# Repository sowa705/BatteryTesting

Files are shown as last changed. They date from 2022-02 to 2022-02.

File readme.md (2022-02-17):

# Simple battery testing tool

This project aims to build a **complete** and affordable setup for DIY battery testing.

## Features

* Compatible with various battery types
* Battery capacity testing
* Internal resistance measurement
* Nice graphs
* Minimal component count, low cost

## Example test result

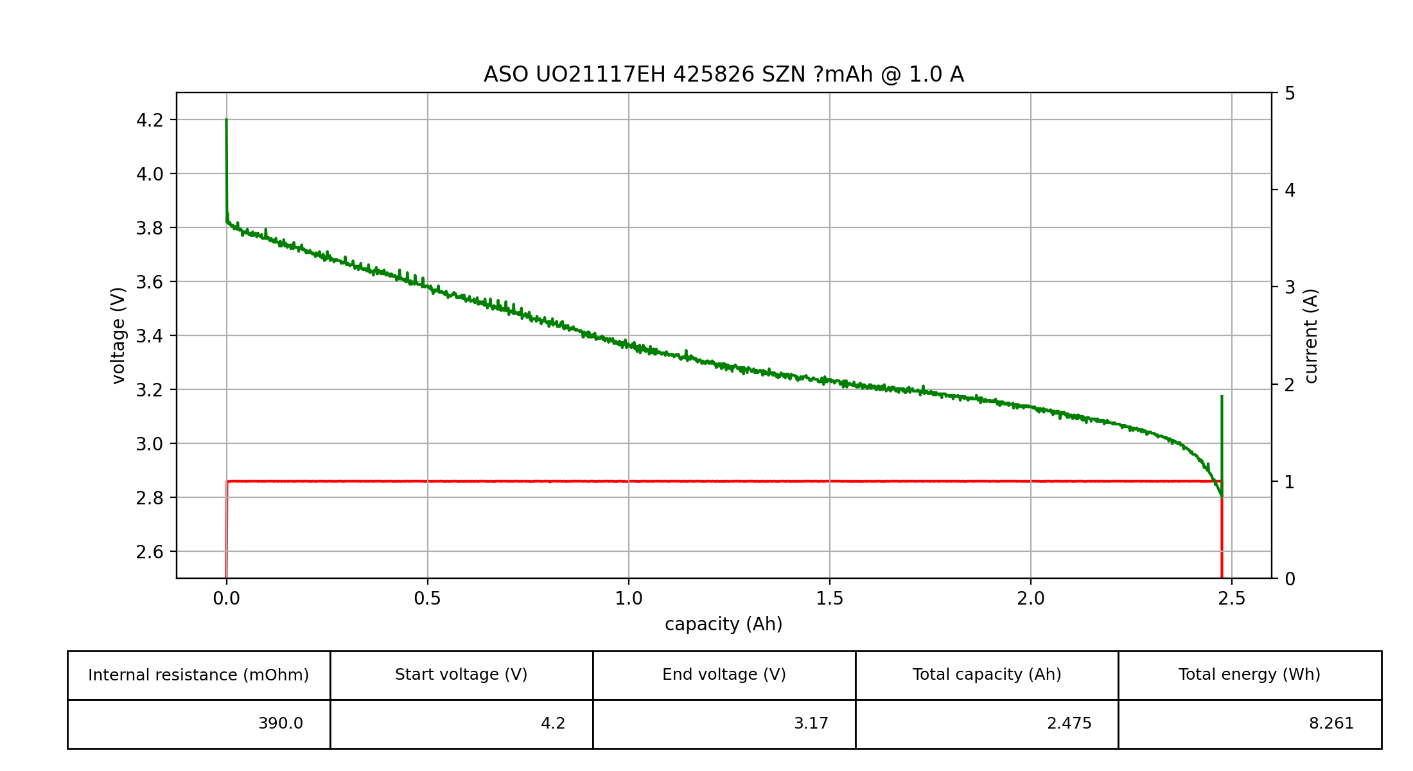
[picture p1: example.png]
Example test result


## Required parts

* Computer with Python 3
* Arduino Uno
* Constant current load (example schematic included in the hardware directory)

## Usage

* Connect all parts together (load is not applied until the software is started)
* Start the measurement with `python .\desktop\measurebattery.py [COM PORT] [CUTOFF VOLTAGE]`
* Battery will be discharged until it reaches specified voltage or *2.8V* if no voltage was specified
* Enter your battery name in the first line of the resulting file ( `battery_[TIME].txt` )
* Render the graph with `python .\desktop\rendergraph.py [FILE NAME]`

## Accuracy

Measurement accuracy depends heavily on how stable your PC USB voltage is, after calibration you should be able to get around 5% accuracy for capacity.

Accurate measurement of internal resistance requires good battery connection and good PCB design for your constant current load, stock design should be able to measure within 10%.

## Contributing

Contributions are welcome, feel free to submit your own test results or hardware/software improvements.

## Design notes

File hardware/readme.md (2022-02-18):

# Hardware

This section is unfinished as I wait for parts for the more advanced board to arrive.

As a temporary solution you can use the circuit in the `manualcurrent` directory

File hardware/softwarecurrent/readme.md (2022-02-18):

# Software current control board design

This directory contains the Eagle PCB design files for the Arduino shield with all required hardware installed

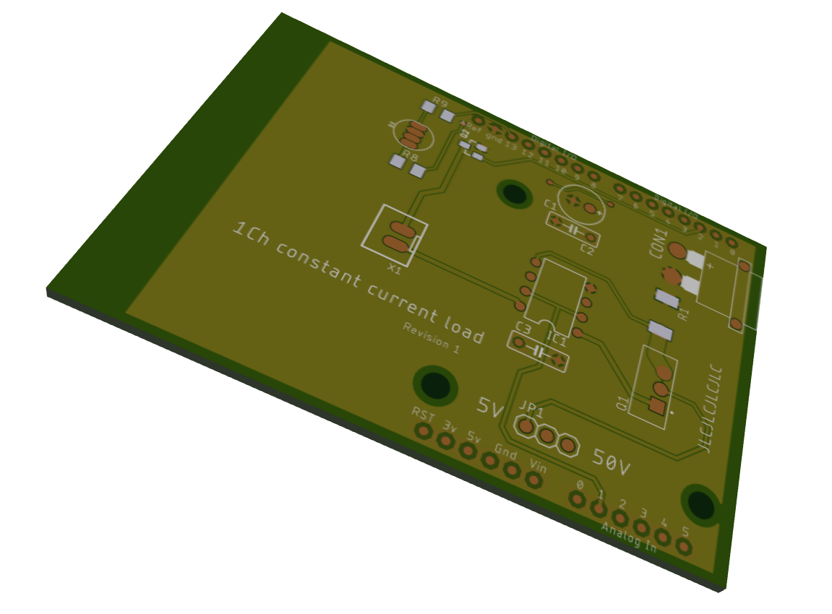
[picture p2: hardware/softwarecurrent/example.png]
PCB picture


## Features

* Arduino shield format
* Software adjustable load
* Wide voltage range (0V - 50V)
* Active cooling

## Support

This PCB isn't yet supported as i wait for it to ship from China, this page will be updated when i get the software and hardware ready to use.

BOM and additional information will be available soon.

## Usage

**If your battery voltage exceeds 5V set the voltage switch to the "50V" position to enable the voltage divider.**

Connect your battery to the XT30 connector on the board, all further setup is done through software.

## Considerations

* This board heavily depends on reliable 5V power supply for the Arduino, with unstable voltage your results may drift considerably
* Watch out for the mosfet temperature, while this board has a fan connector you can easily overload it by discharging high currents from high voltage batteries

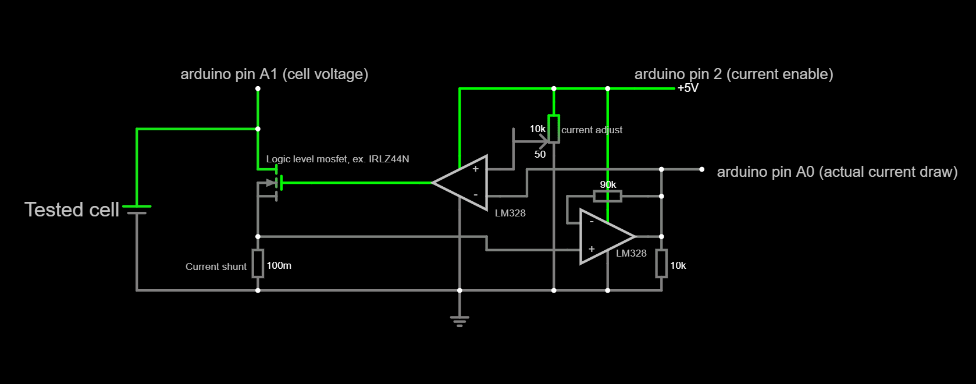
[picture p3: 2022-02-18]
hardware/manualcurrent/basicschematic.png

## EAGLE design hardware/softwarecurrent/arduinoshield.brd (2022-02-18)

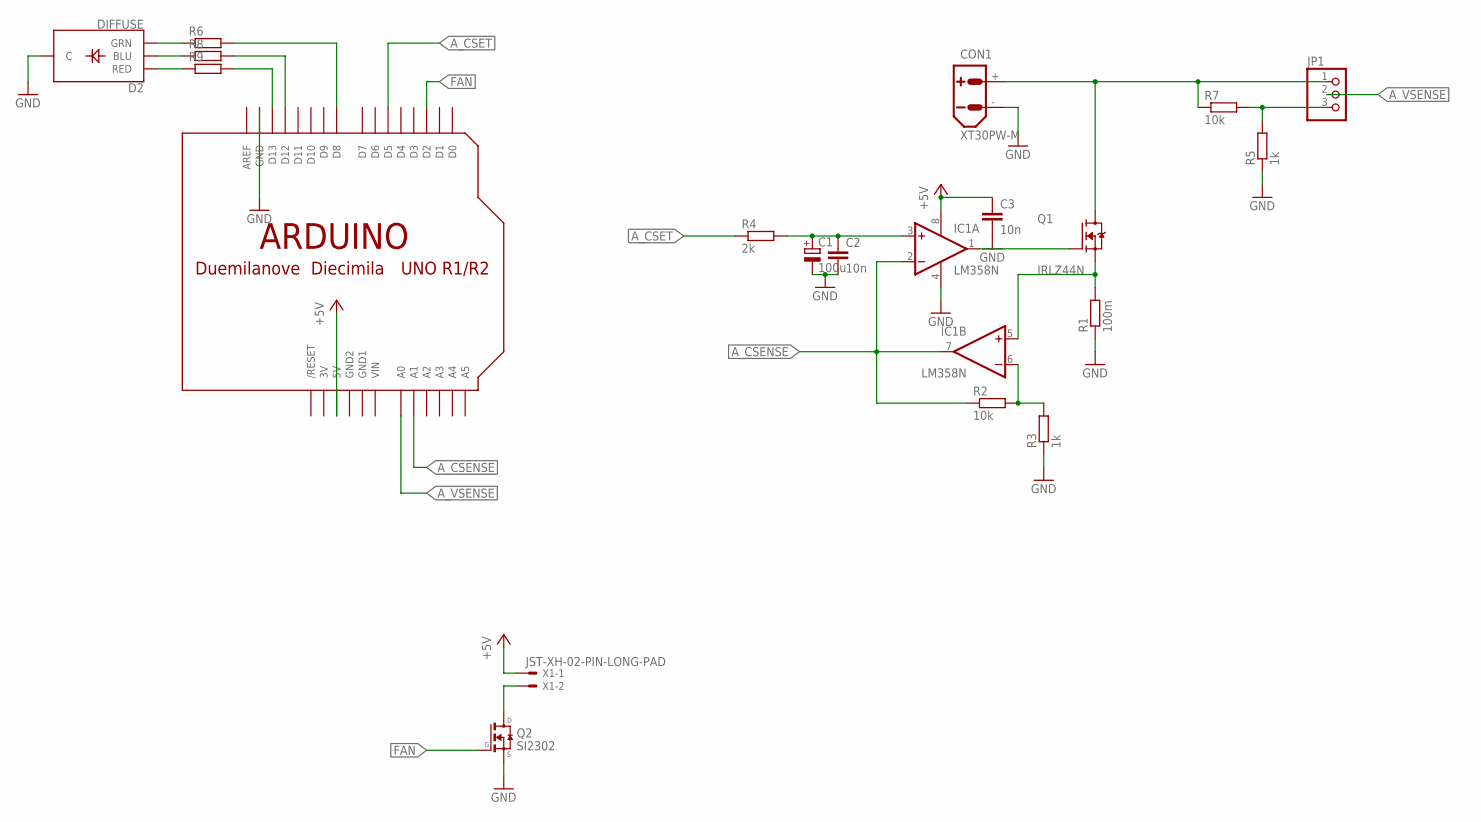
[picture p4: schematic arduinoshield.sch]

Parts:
C1: 100u; E2,5-7
C2, C3: 10n; C050-025X075
CON1: XT30PW-M
D2: DIFFUSE; LED-RGB-THRU
IC1: LM358N; DIL08
JP1: PINHD-1X3; 1X03
Q1: IRLZ44N; TO254P1054X469X1930-3
Q2: SI2302; SOT23
R1: 100m; R2512
R2, R7: 10k; M1206
R3, R5: 1k; M1206
R4: 2k; M1206
R6, R8, R9: R-EU_M1206; M1206
U$2: ARDUINO-NOHOLE
X1: JST-XH-02-PIN-LONG-PAD; JST-XH-02-PACKAGE-LONG-PAD

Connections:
3V: U$2.3V
+5V: C3.1, IC1.8 (V+), U$2.5V, X1.1
A_CSENSE: IC1.2 (-IN), IC1.7 (OUT), R2.1, U$2.A1
A_CSET: R4.1, U$2.D5
A_VSENSE: JP1.2, U$2.A0
FAN: Q2.1 (G), U$2.D2
GND: C1.-, C2.2, C3.2, CON1.-, D2.2 (C), IC1.4 (V-), Q2.2 (S), R1.1, R3.1, R5.1, U$2.GND
GND1: U$2.GND1
GND2: U$2.GND2
unnamed: IC1.5 (+IN), Q1.3 (S), R1.2
unnamed: CON1.+, JP1.1, Q1.2 (D), R7.1
unnamed: JP1.3, R5.2, R7.2
unnamed: IC1.1 (OUT), Q1.1 (G)
unnamed: C1.+, C2.1, IC1.3 (+IN), R4.2
unnamed: IC1.6 (-IN), R2.2, R3.2
unnamed: Q2.3 (D), X1.2
unnamed: D2.3 (GRN), R6.1
unnamed: D2.4 (BLU), R8.1
unnamed: D2.1 (RED), R9.1
unnamed: R6.2, U$2.D8
unnamed: R8.2, U$2.D12
unnamed: R9.2, U$2.D13
VIN: U$2.VIN

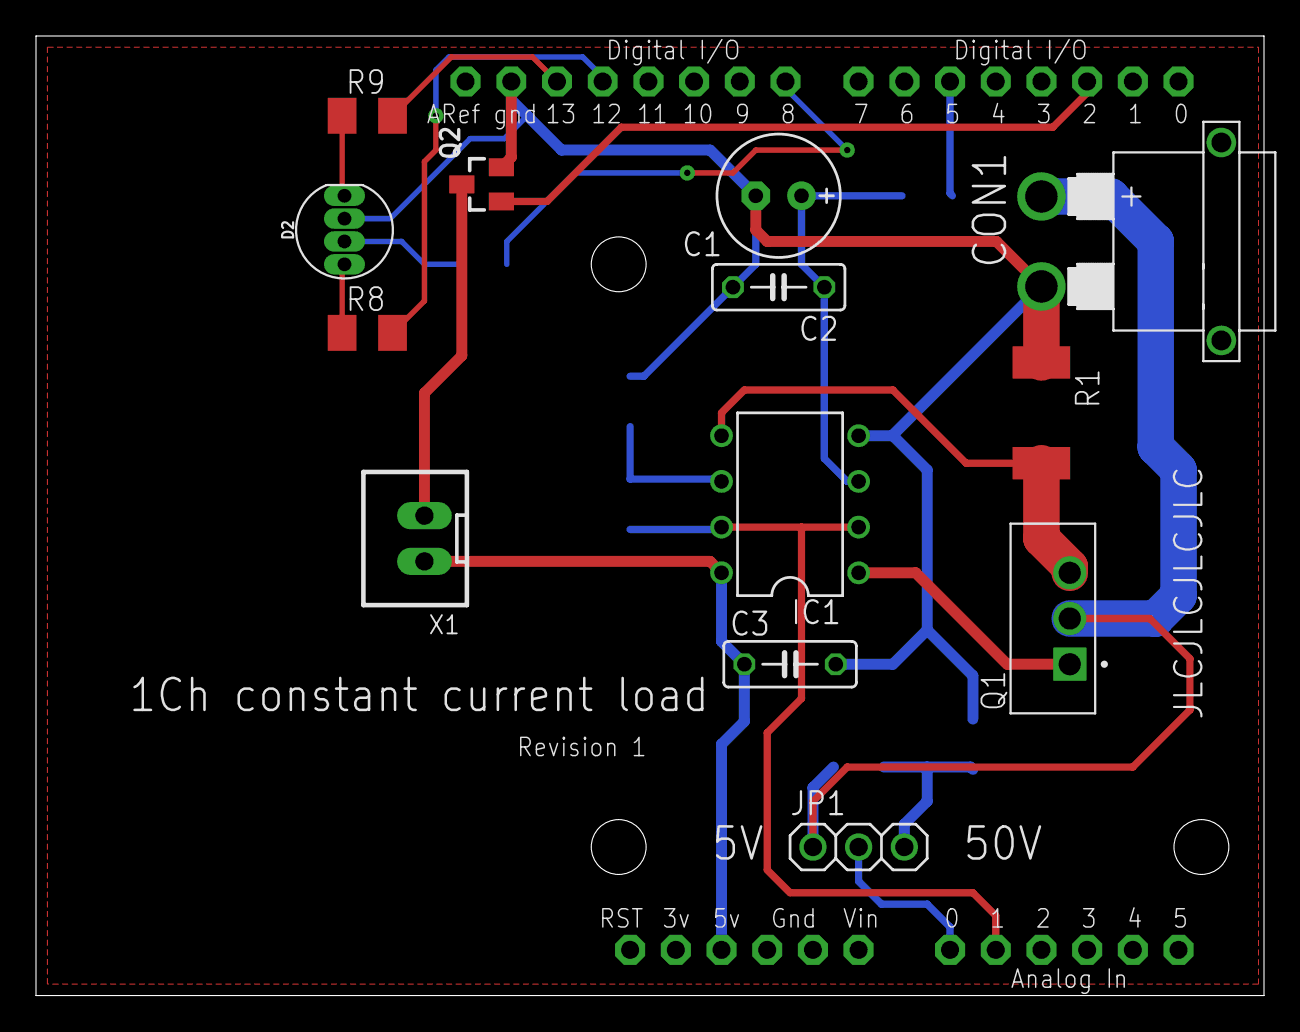
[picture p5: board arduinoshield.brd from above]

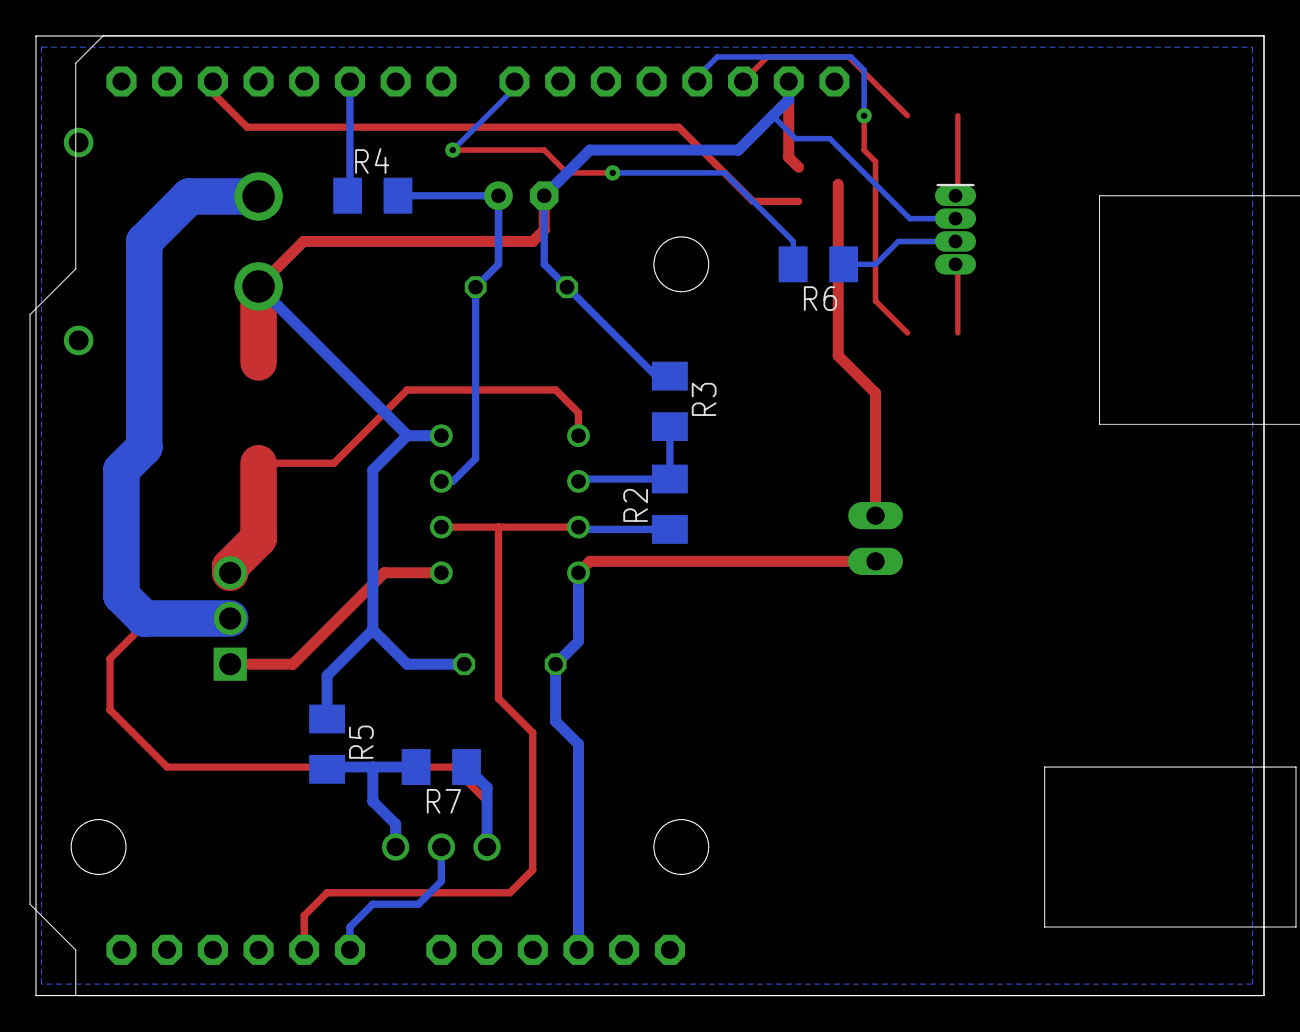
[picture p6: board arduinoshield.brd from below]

Board: 2 copper layers, 68.2 x 53.3 mm, 20 parts (6 on the bottom side), 19 nets.

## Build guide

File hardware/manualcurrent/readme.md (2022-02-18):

# Manual current schematic

This simplified schematic shows the setup used for measurements, the discharge current is set manually with a potentiometer

**All measurements in this repo were made with this board**

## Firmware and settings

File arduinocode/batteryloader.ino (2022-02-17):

//set this to your current shunt resistance in ohms
float shuntResistance=1;
//current shunt voltage amplification
float currentGain=1;

float voltageCalibrationData[4] = {1.0,4.0,1.0,4.0};
float amperageCalibrationData[4] = {0.0,4,0.0,4.0};

void setup() {
  Serial.begin(9600);
  pinMode(2,OUTPUT);
}

int readAnalog(int port){
  int total=0;
  for(int i=0;i<3;i++){
    total+=analogRead(port);
    delay(50);
  }
  return total/3;
}

float correct(float val, float* calibrationData){
  return mapf(val,calibrationData[0],calibrationData[1],calibrationData[2],calibrationData[3]);
}

float mapf(float x, float in_min, float in_max, float out_min, float out_max) {
  return (x - in_min) * (out_max - out_min) / (in_max - in_min) + out_min;
}

float readVoltage(){
  float readout=readAnalog(A1)/1024.0*5;
  readout=correct(readout,voltageCalibrationData);
  return readout;
}
float readAmperage(){
  float readout=readAnalog(A0)/1024.0*5/shuntResistance*currentGain;
  readout=correct(readout,amperageCalibrationData);
  return readout;
}

void sendReading(){
  float vbatt=readVoltage();
  float ibatt=readAmperage();
  Serial.print(vbatt, 4);
  Serial.print(",");
  Serial.println(ibatt, 4);
}

void sendCalTable(float* calibrationData){
  Serial.print(calibrationData[0], 4);
  Serial.print(",");
  Serial.print(calibrationData[1], 4);
  Serial.print(",");
  Serial.print(calibrationData[2], 4);
  Serial.print(",");
  Serial.print(calibrationData[3], 4);
  Serial.println(";");
}

void loop() {
  if (Serial.available() > 0) {
    int incomingByte = Serial.read();
    switch(incomingByte){
      case 'r':
        sendReading();
      break;
      case 'e':
        digitalWrite(2,1);
      break;
      case 'd':
        digitalWrite(2,0);
      case 'a':
        sendCalTable(amperageCalibrationData);
        break;
      case 'v':
        sendCalTable(voltageCalibrationData);
        break;
    }
  }
  
 
  delay(50);
}

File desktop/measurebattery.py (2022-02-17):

import serial
import time
import sys

args=sys.argv[1:]
if len(args)==0:
    print("Provide serial port")
    exit()

arduinoport=args[0]

cutoff_v=2.8

if len(args)==2:
    cutoff_v=float(args[1])

arduino = serial.Serial(port=arduinoport, baudrate=9600, timeout=.5)

def write_read(x):
    arduino.write(bytes(x, 'utf-8'))
    time.sleep(0.2)
    data = arduino.readline()
    return data.decode("utf-8")

def readvoltamps():
    ret=write_read("r")
    splittext=ret.split(",")
    volts=float(splittext[0])
    amps=float(splittext[1])
    return (volts,amps)

def readvolts():
    ret=write_read("r")
    splittext=ret.split(",")
    volts=float(splittext[0])
    amps=float(splittext[1])
    return volts

def getintres():
    write_read("d")
    time.sleep(2)
    start=readvoltamps()
    time.sleep(1)
    write_read("e")
    time.sleep(2)
    end=readvoltamps()
    write_read("d")
    start_v,start_a=start
    end_v,end_a=end
    voltdiff=start_v-end_v
    print(start)
    print(end)
    return int(voltdiff/end_a*1000)

file=open(f"battery_{int(time.time())}.txt","w")
time.sleep(2)
vres=f"starting voltage: {readvolts()} V"
res=f"internal resistance: {getintres()} mOhm"
print(vres)
print(res)
file.write("Battery name\n")
file.write(vres+"\n")
file.write(res+"\n")

write_read("e")
ah=0
wh=0
lasttime=time.time()
starttime=lasttime
while True:
    time.sleep(5)
    readraw=write_read("r")

    splittext=readraw.split(",")
    volts=float(splittext[0])
    amps=float(splittext[1])

    diff=time.time()-lasttime
    lasttime=time.time()
    ah+=amps*diff/60/60
    wh+=amps*volts*diff/60/60
    read=f"{readraw.strip()},{time.time()-starttime},{ah},{wh};"

    if volts<cutoff_v:
        print(f"Ending measurement, voltage too low: {volts}")
        write_read("d")
        time.sleep(5)
        volts=readvolts()
        file.write(f"ending voltage: {volts} V")
        break

    print(read)
    file.write(read+"\n")

file.close()

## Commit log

2022-02-17 Delete battery.py
    duplicate file
2022-02-17 LGDB218650 battery added
2022-02-18 additional information
    [arduinoshield.brd, arduinoshield.sch]

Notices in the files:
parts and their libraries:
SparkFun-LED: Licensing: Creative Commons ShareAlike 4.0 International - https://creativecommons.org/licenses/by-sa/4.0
